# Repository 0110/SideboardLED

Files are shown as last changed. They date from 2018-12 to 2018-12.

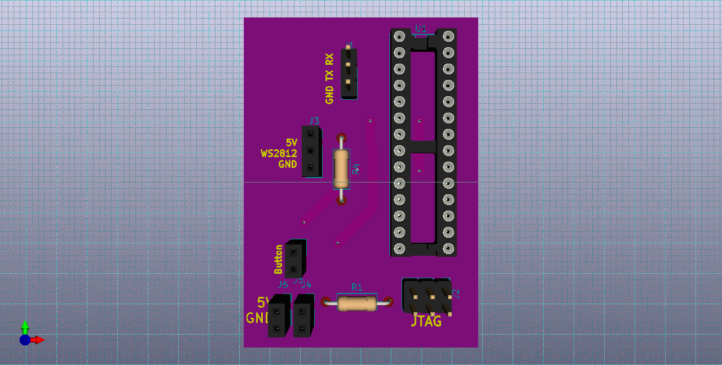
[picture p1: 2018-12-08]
board/LEDatmega.png

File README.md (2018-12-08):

# SideboardLED
Sprit: ollpe never dies

Another tiny project to control a WS2812 stripe via an Arduino based microcontroller.
## Hardware
* Atmega8
* 75 WS2812LEDs
* USB Serial converter

Programmer, e.g.:
* AVRISPmkii

## Software
### Arduino

In order to flash the software, select the following settings in Arduino:
* Tools | Board "Arduino NG or older"
* Tools | Processor "Atmega8"
* Sketch | Export Compiled Binary

In your arduino installtion, update the CPU frequency, as we are using the internal clock with 8Mhz.
Find the following file */hardware/arduino/avr/boards.txt*.
Inside the file, search for the chapter **Arduino NG or older w/ ATmega8** and add the following line:
```
atmegang.menu.cpu.atmega8.build.f_cpu=8000000L
```

### Avrdude
The flashing itself is done with **avrdude**:
```bash
avrdude -c AVRISPmkii -p m8 -u -U flash:w:SideboardLED.ino.standard.hex
```
Initial once the fuses must be burned:
```bash
avrdude -c avrispmkii -p atmega8 -U lfuse:w:0xe4:m -U hfuse:w:0xd9:m -U efuse:w:0xfc:m
```

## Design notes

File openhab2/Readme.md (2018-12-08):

# OpenHAB
Some OpenHAB 2 examples

## Requirements
* OpenHAB2
* Serial Binding

## Configuration

On a raspberry, give the *openhab* user access to the serial interfaces:
```bash
sudo usermod -a -G dialout openhab
```

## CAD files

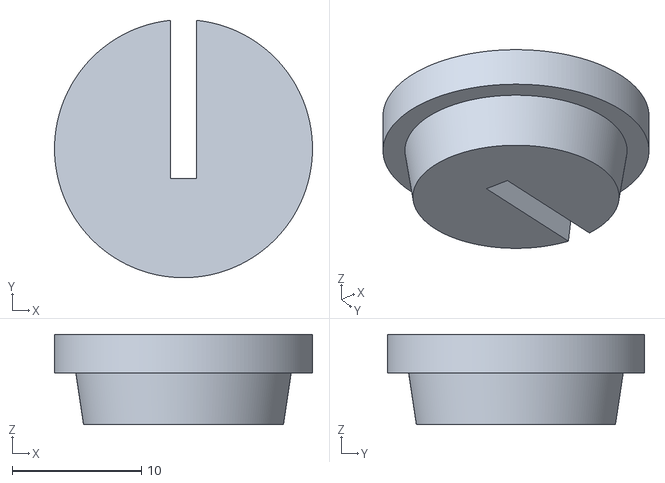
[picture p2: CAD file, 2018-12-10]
3dprinted/LEDend.stl
20.0 x 19.9 x 7.00

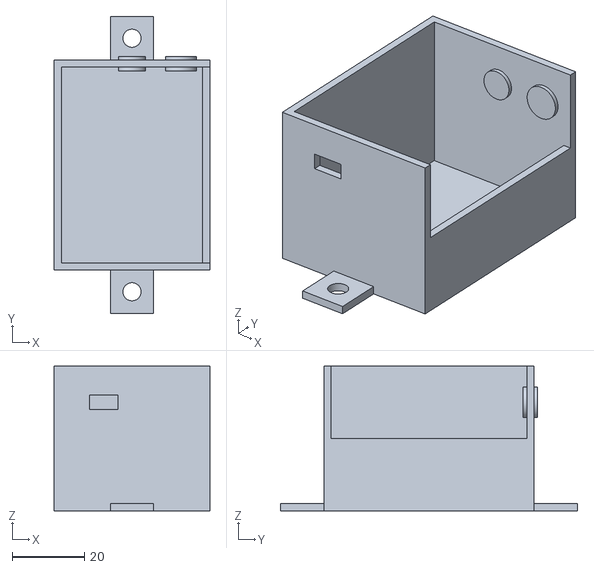
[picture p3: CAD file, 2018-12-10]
3dprinted/LEDboardHousing.stl
43.0 x 82.0 x 40.0

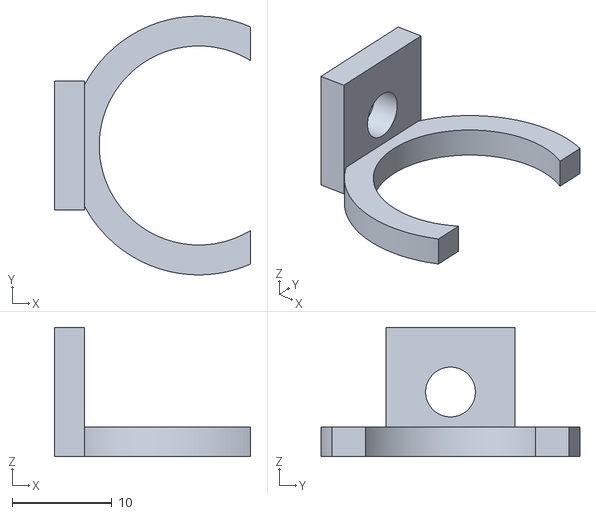
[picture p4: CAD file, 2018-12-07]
3dprinted/LEDclip.stl
19.7 x 26.0 x 13.0

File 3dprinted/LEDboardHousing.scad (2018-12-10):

boardWidth=39;
boardDeepth=54;
wallWidth=2;
wallHeight=40;
wallHeightTop=20;
// connectors
buttonHole=7.5;
powerHole=8.5;
// USB mount
usbWidth=8;
usbHeight=4;

// box mount
drill=5;


cube([boardWidth,boardDeepth,wallWidth], center=true);
// right
translate([boardWidth/2+wallWidth/2,0,wallHeightTop/2-wallWidth/2]) cube([wallWidth,boardDeepth, wallHeightTop], center=true);
// left
translate([-(boardWidth/2+wallWidth/2),0,wallHeight/2-wallWidth/2]) cube([wallWidth,boardDeepth, wallHeight], center=true);
// top
translate([0,boardDeepth/2+wallWidth/2,wallHeight/2-wallWidth/2]) union() {
    cube([boardWidth+2*wallWidth,wallWidth, wallHeight], center=true);
    // power
    translate([boardDeepth*0.25, 0,wallHeight*0.25]) rotate([90,90,0]) cylinder(d=powerHole, h=wallWidth*2, center=true, $fn=180);
    // button
    translate([0, 0,wallHeight*0.25]) rotate([90,90,0]) cylinder(d=buttonHole, h=wallWidth*2, center=true, $fn=180);

}
// buttom
translate([0,-(boardDeepth/2+wallWidth/2),wallHeight/2-wallWidth/2]) difference() {
    cube([boardWidth+2*wallWidth,wallWidth, wallHeight], center=true);
    translate([-boardWidth*0.20, 0,wallHeight*0.25]) cube([usbWidth, 2*wallWidth, usbHeight], center=true);
}

// Mount to the Sideboard
translate([0,boardDeepth/2+wallWidth+(drill*2+wallWidth)/2,0]) difference() {
cube([drill*2+wallWidth,drill*2+wallWidth,wallWidth], center=true);
    cylinder(d=(drill), h=wallWidth*2, center=true, $fn=180);
}
translate([0,-(boardDeepth/2+wallWidth+(drill*2+wallWidth)/2),0]) difference() {
cube([drill*2+wallWidth,drill*2+wallWidth,wallWidth], center=true);
    cylinder(d=(drill), h=wallWidth*2, center=true, $fn=180);
}

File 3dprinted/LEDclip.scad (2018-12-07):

// Define all parameter
tupeDiameter=20;
materialWidth=3;
drill=5;
percentOpen=30;


// Clip
outsideDiameter=(tupeDiameter+materialWidth*2);
difference() {
cylinder(d=outsideDiameter, h=materialWidth, center=true, $fn=180);
    union() {
        cylinder(d=(tupeDiameter), h=materialWidth, center=true, $fn=180);
        translate([outsideDiameter*(100-percentOpen)/100,0,0]) cube([outsideDiameter,outsideDiameter,materialWidth*2], center=true);
    }
}
// Mount to the Sideboard

translate([-outsideDiameter/2,0,drill]) difference() {
cube([materialWidth,drill*2+materialWidth,drill*2+materialWidth], center=true);
    rotate([0,90,0]) cylinder(d=(drill), h=materialWidth*2, center=true, $fn=180);
}

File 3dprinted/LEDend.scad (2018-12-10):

// Define all parameter
tupeDiameter=20;
tupeInsideDiameter=15.5;
tupeInsideDiameter2=17;
materialWidth=3;
materialWidthInside=5;
cableHole=2;
percentOpen=65;


// Cover

difference() {
union() {
    translate([0,0,-materialWidth/2]) cylinder(d1=tupeInsideDiameter, d2=tupeInsideDiameter2, h=materialWidthInside, center=true, $fn=200);
        translate([0,0,materialWidth/2]) cylinder(d=tupeDiameter, h=materialWidth, center=true, $fn=180);
    }
    union() {
        translate([0,tupeInsideDiameter*(100-percentOpen)/100,0]) cube([cableHole,tupeInsideDiameter,materialWidth*3], center=true);
    }
}

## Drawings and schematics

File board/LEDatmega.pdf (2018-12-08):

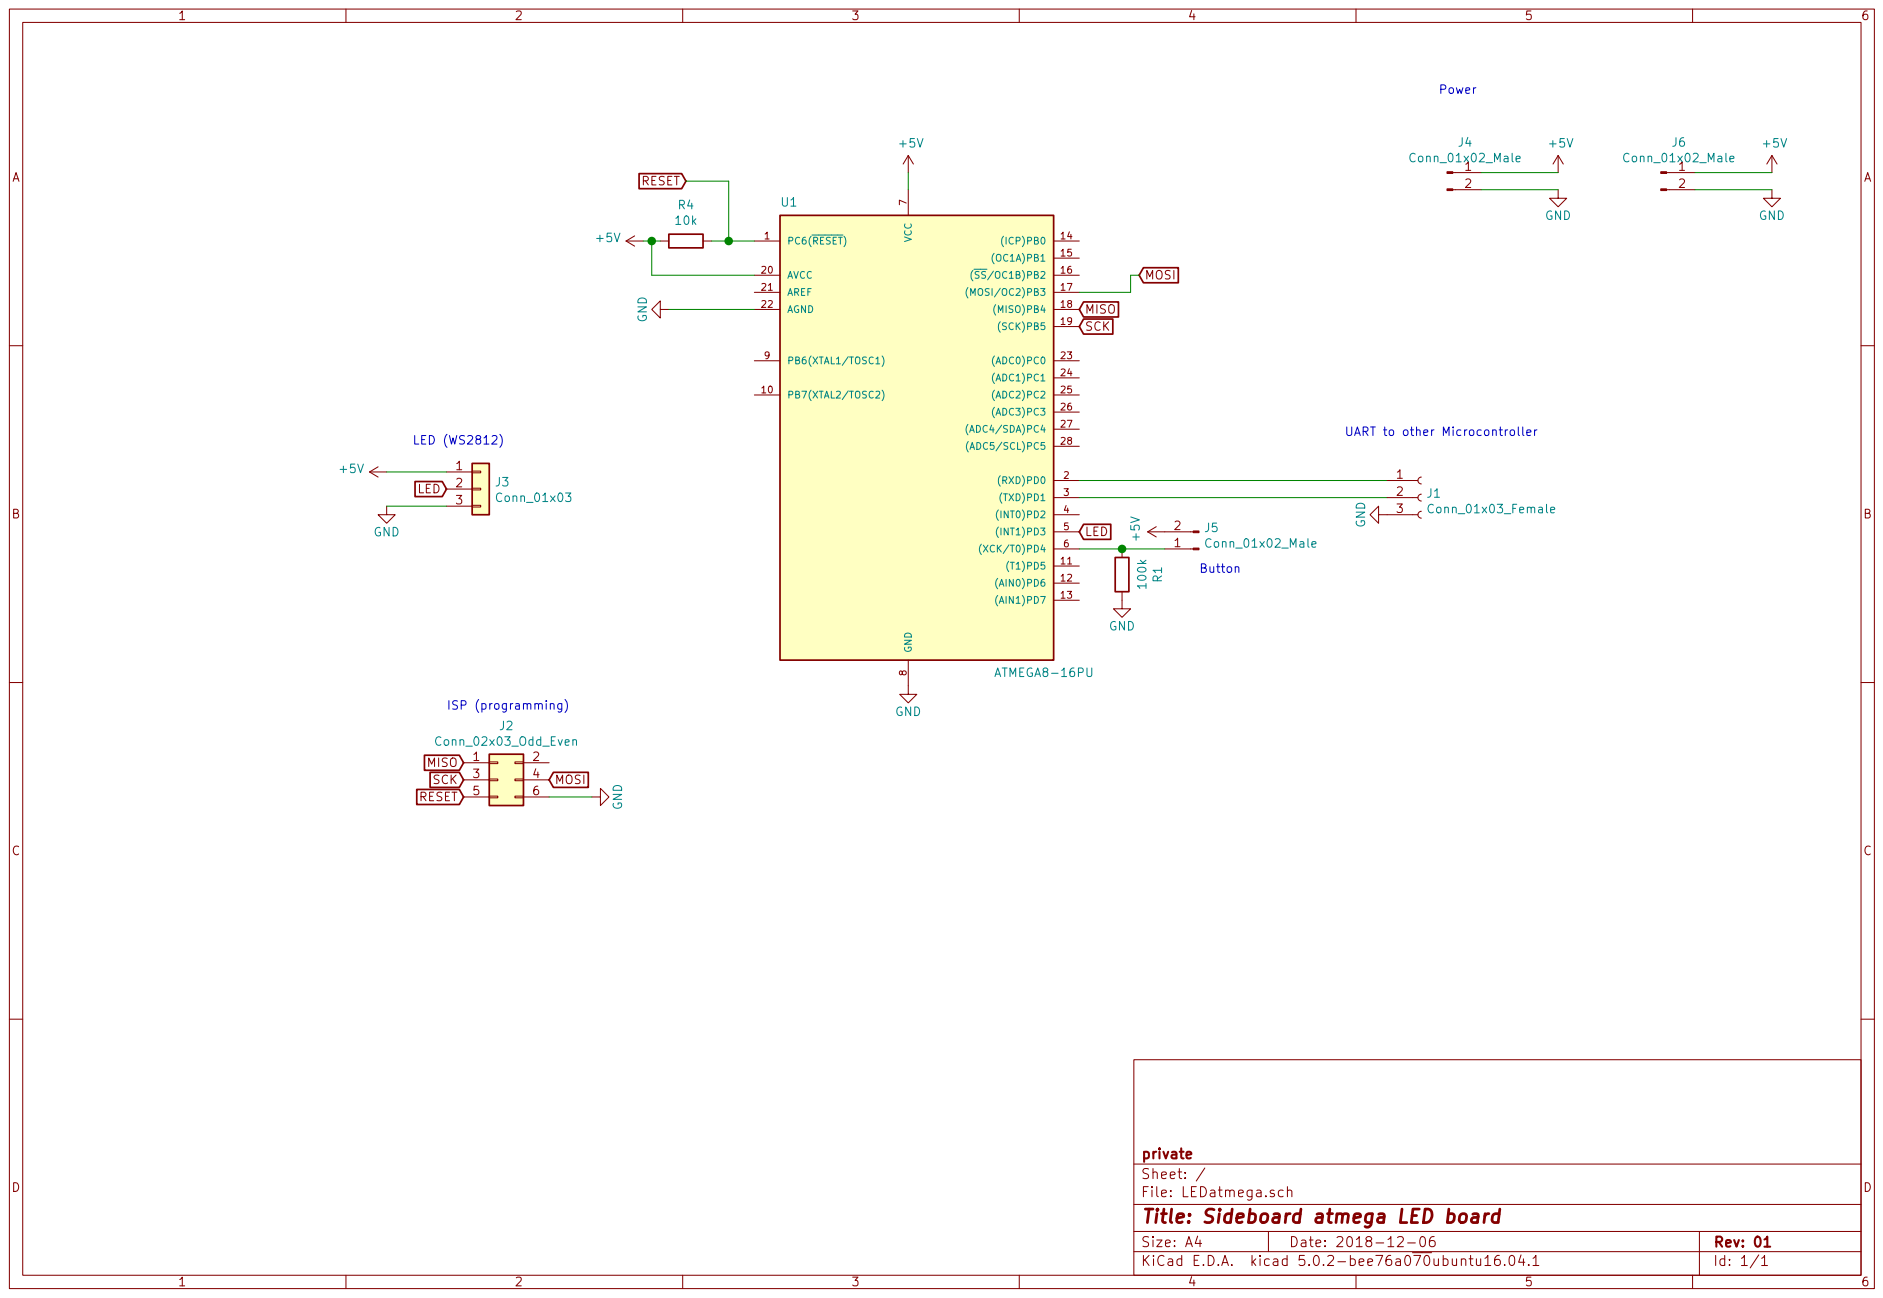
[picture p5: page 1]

File: LEDatmega.sch Sheet: / private

Id: 1/1 Title: Sideboard atmega LED board

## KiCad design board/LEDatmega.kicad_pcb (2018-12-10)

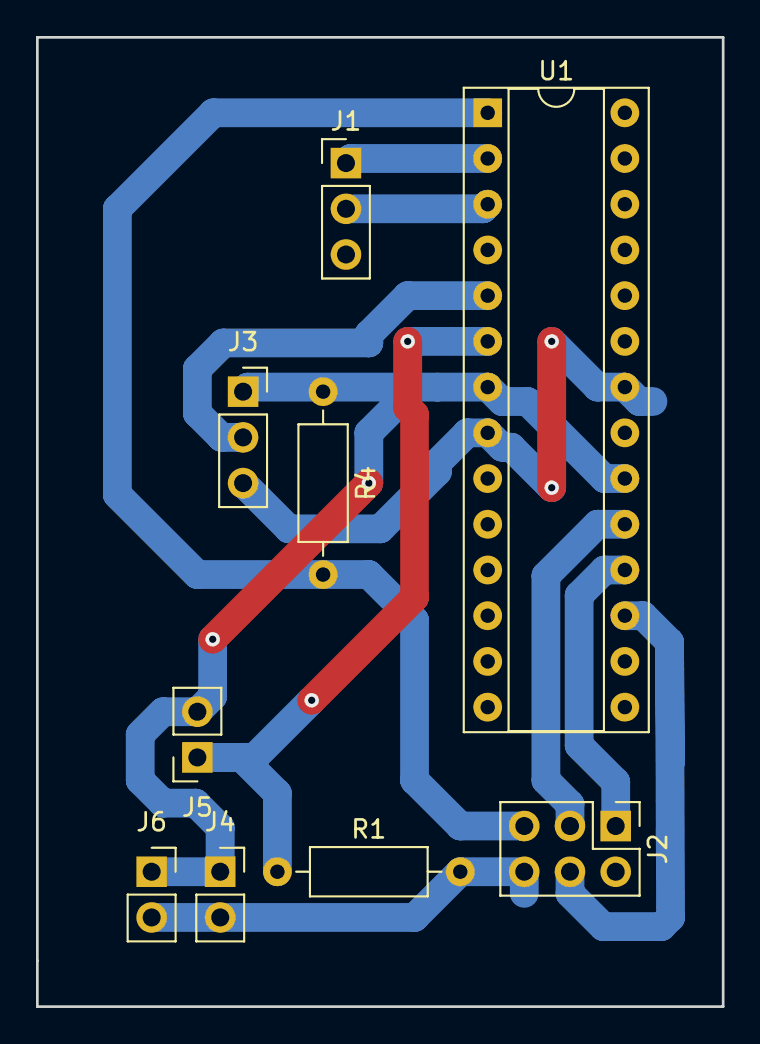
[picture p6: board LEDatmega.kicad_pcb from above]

Board: 2 copper layers, 38.1 x 53.8 mm, 9 parts (0 on the bottom side), 10 nets.

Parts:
J1: Conn_01x03_Female; PinHeader_1x03_P2.54mm_Vertical
J2: Conn_02x03_Odd_Even; PinHeader_2x03_P2.54mm_Vertical
J3: Conn_01x03; PinSocket_1x03_P2.54mm_Vertical
J4, J5, J6: Conn_01x02_Male; PinSocket_1x02_P2.54mm_Vertical
R1: 100k; R_Axial_DIN0207_L6.3mm_D2.5mm_P10.16mm_Horizontal
R4: 10k; R_Axial_DIN0207_L6.3mm_D2.5mm_P10.16mm_Horizontal
U1: ATMEGA8-16PU; DIP-28_W7.62mm_Socket

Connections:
+5V: J3.1, J4.1, J5.2, J6.1, R4.1, U1.7, U1.20
GND: J1.3, J2.6, J3.3, J4.2, J6.2, R1.2, U1.8, U1.22
LED: J3.2, U1.5
MISO: J2.1, U1.18
MOSI: J2.4, U1.17
unnamed: J1.1, U1.2
unnamed: J1.2, U1.3
unnamed: J5.1, R1.1, U1.6
RESET: J2.5, R4.2, U1.1
SCK: J2.3, U1.19

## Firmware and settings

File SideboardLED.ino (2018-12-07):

/*
   Fuses:
   avrdude -c avrispmkii -p atmega8 -U lfuse:w:0xee:m -U hfuse:w:0xd9:m -U efuse:w:0xfc:m

   Arduino Settings:
   Board: Arduino NG / or older
   Processor: Atmega8
*/

#include <FastLED.h>

/****************** LED output ***********************/

#define LED_PIN     3

// Information about the LED strip itself
#define NUM_LEDS    45  /* aka 75cm at 60LEDs per 100cm */
#define CHIPSET     WS2812
#define COLOR_ORDER GRB
CRGB leds[NUM_LEDS];
CRGBSet ledset(leds, NUM_LEDS);

#define BRIGHTNESS  128   /** Average brightness, that shall not exeeded */
#define FADEBLACK   -2

#define PIN_BUTTON 4      /** PD4 = Input for button */

/****************** Command line ***********************/
int CMD_MAX = 128;
char myCmd[128];

void setup() {
  // start serial port at 9600 bps:
  Serial.begin(9600);
  Serial.println("Sideboard LED running...");
  // It's important to set the color correction for your LED strip here,
  // so that colors can be more accurately rendered through the 'temperature' profiles
  FastLED.addLeds<CHIPSET, LED_PIN, COLOR_ORDER>(leds, NUM_LEDS);

  pinMode(PIN_BUTTON, INPUT);        // sets the digital pin 7 as input
  
  // Turn the LED on, then pause
  leds[0] = CRGB::Red;
  FastLED.show();
  delay(500);
  // Now turn the LED off, then pause
  leds[0] = CRGB::Black;
  FastLED.show();
  delay(500);
}

void clearCmdArray(){
  //clear the cmd array
  for (int i = 0; i < CMD_MAX; i++){
    myCmd[i] = '\0';
  }
}

  //returns number of read bytes
  int readFromSerialIntoCmdArray(){ 
  //read from the serial buffer and flush
  int inputSize = Serial.available();
  
  //give serial a chance to receive all bytes
  if(inputSize > 0){
    delay(100);
    inputSize = Serial.available();
  }
  
  if(inputSize > 0 && inputSize < CMD_MAX){
    Serial.print("inputSize: ");
    Serial.println(inputSize);
    for (int i = 0; i < inputSize; i++){
      myCmd[i] = Serial.read();
    }
  }else if(inputSize >= CMD_MAX){
   Serial.flush();
   Serial.println("too much data, flush");
  }
  return inputSize;
}

//check if command has the required prefix
int checkCmdArrayForPrefix(){
   if (myCmd[0] == 'o'
     && myCmd[1] == 'l'
     && myCmd[2] == 'l'
     && myCmd[3] == 'p'
     && myCmd[4] == 'e'){
      return 1;
   }
  return 0;
}

void sendAckOverSerial(){
  Serial.println(F("ACK"));
}

void sendNackOverSerial(){
  Serial.println(F("NACK"));
}

void sendPingAckOverSerial(){
  Serial.println(F("PACK"));
}

/**
 * Extract the color from the given LED command
 */
void parseColor(char* pCmd, CRGB *pColor) {
  unsigned int colorParts[3]; /* 0: red, 1: green, 2: blue */
  unsigned int colorSum = 0;
  for(int i=0; i < (2*3); i+= 2) {
    colorParts[i/2] = (pCmd[i] <= '9') ? ((pCmd[i]-'0') << 4) : (((pCmd[i]-'A')+10) << 4);
    if (colorParts[i/2] < 0) { Serial.print("calcErr:"); Serial.println(colorParts[i/2]); }
    colorParts[i/2] += (pCmd[i+1] <= '9') ? ((pCmd[i+1]-'0')) : (((pCmd[i+1]-'A')+10));
  }
  pColor->r = colorParts[0]; /* fill red */
  pColor->g = colorParts[1]; /* fill green */
  pColor->b = colorParts[2]; /* fill blue */

  colorSum = pColor->r;
  colorSum += pColor->g;
  colorSum += pColor->b;
  /* Generate the average brightness */
  colorSum = (colorSum / 3);
  if (colorSum > BRIGHTNESS) {
    /* scale the brightness, if the values are too high */
    pColor->r = pColor->r * BRIGHTNESS / colorSum;
    pColor->g = pColor->g * BRIGHTNESS / colorSum;
    pColor->b = pColor->b * BRIGHTNESS / colorSum;
  }
}

/*
 * Give the user some helpfull advice.
 * (Text is stored in the flash to save RAM of the Arduino)
 */
void sendHelpOverSerial()
{
  Serial.println(F("----help is coming----"));
  Serial.println(F("all commands must be prefixed with \"ollpe\""));
  Serial.println(F("----commands----"));
  Serial.println(F("axxxxxx\t set all leds to RRGGBB (hex: 0-9A-F)"));
  Serial.println(F("w00xxxxxx\t set led 0 (first) to RRGGBB (hex: 0-9A-F)"));  
  Serial.println(F("r00\t returns state of led 0 (first)"));
  Serial.println(F("c\t clear all leds (000000h)"));
  Serial.println(F("m\t magic rainbow for all leds until next command is received"));
  Serial.println(F("ping\t returns \"PACK\""));
  Serial.println(F("help\t prints this help"));
  Serial.println(F("----help end----"));
}

void loop() { 
  /* spcial rainbow mode */
  static int rainbowIndex = -1;
  static CRGB color;
  if (rainbowIndex < 0) {
    //delay needed to have a chance to get the whole message
    delay(200);
    clearCmdArray();
    if (rainbowIndex == FADEBLACK) {
      ledset.fadeToBlackBy(40);
    }
    FastLED.show();
  } else {
    if (rainbowIndex >= 255) {
      /* one byte used -> simulate overflow */
      rainbowIndex=0;
    }
    ledset.fill_rainbow(rainbowIndex++);
    // Dim a color by 25% (64/256ths)
    ledset.fadeLightBy( 60 );
    FastLED.delay(30);
  }

  // check if button was pressed
  if (digitalRead(PIN_BUTTON)) {
    Serial.println(F("BTN"));
    rainbowIndex=0; /* activate rainbow */
  }
 
  int inputSize = readFromSerialIntoCmdArray();
  if (inputSize > 0)
  {
    rainbowIndex=-1; /* command -> deactivate rainbow */
    int checkCmd = checkCmdArrayForPrefix();
    if(checkCmd == 0){
       Serial.println(F("if you dont know what to do type \"ollpehelp\""));
       sendNackOverSerial();
       return; 
    } else if(myCmd[5] == 'p' 
            && myCmd[6] == 'i' 
            && myCmd[7] == 'n' 
            && myCmd[8] == 'g')
    {
       sendPingAckOverSerial();
    }
    else if(myCmd[5] == 'h' 
            && myCmd[6] == 'e' 
            && myCmd[7] == 'l' 
            && myCmd[8] == 'p')
    {
       sendHelpOverSerial();
    }
    else if(myCmd[5] == 'a')
    {
      parseColor(myCmd+6, &color);
      ledset.fill_solid(color);
      sendAckOverSerial();
    }
    else if(myCmd[5] == 'c')
    {
      rainbowIndex = FADEBLACK;
      sendAckOverSerial();
    }
    else if(myCmd[5] == 'm')
    {
      rainbowIndex=0; /* activate rainbow */
      Serial.println(F("Rainbow"));
      sendAckOverSerial();
    }
    else if(myCmd[5] == 'w')
    {
      int index = (myCmd[6]-'0') * 10 + (myCmd[7]-'0');
      if (index > NUM_LEDS) {
        Serial.println(F("Index too large"));
        sendNackOverSerial();
      } else {
        parseColor(myCmd+8, &color);
        leds[index] = color;
        sendAckOverSerial();
      }
    }
    else if(myCmd[5] == 'r')
    {
      int index = (myCmd[6]-'0') * 10 + (myCmd[7]-'0');
      if (index > NUM_LEDS) {
        sendNackOverSerial();
      } else {
       Serial.println(leds[index]);
        sendAckOverSerial();
      }
    }
  }
}

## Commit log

2018-12-06 Initial KiCAD project of the hardware board
    [LEDatmega.kicad_pcb, LEDatmega.sch]
2018-12-06 Replaced USBtty connector with 6pin one
    [LEDatmega.sch]
2018-12-07 Layouting done
    [LEDatmega.kicad_pcb, LEDatmega.sch]
2018-12-07 Generating of board
2018-12-07 Moved board in the upper left corner
    [LEDatmega.kicad_pcb]
2018-12-07 Clip for Sideboard mount
    [LEDclip.scad, LEDclip.stl]
2018-12-07 Included Button to start rainbow
2018-12-07 End mount of LED holder
    [LEDend.scad, LEDend.stl]
2018-12-08 LED board house
    [LEDboardHousing.scad, LEDboardHousing.stl]
2018-12-08 Only 3pin connector for Serial interface
    [LEDatmega.kicad_pcb, LEDatmega.sch]
2018-12-08 Added export of schematics and board
2018-12-08 OpenHAB integration described
    [LEDatmega.sch]
2018-12-10 Higher walls and bigger ground
    [LEDboardHousing.scad, LEDboardHousing.stl]
2018-12-10 longer end plug
    [LEDend.scad, LEDend.stl]
2018-12-10 Added board dimensions into layout
    [LEDatmega.kicad_pcb]
